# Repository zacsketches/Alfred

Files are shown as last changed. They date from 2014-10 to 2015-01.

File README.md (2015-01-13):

#Alfred

My Glow Worm Arduino based robotics framework on a Dagu Rover5 
platform.

The Alfred_master file contains the most advanced sketch that 
integrates the ultrasonic sensor with the bump sensors and
a light plant to provide some feedback on where the robot is
sensing obstructions.

Unfortunately, **AND THIS IS BIG**, I had to change the buffer size in
wire.h, twi.h, and hardwareSerial.h located in the Arduino libraries
in order to create enough room for this code to load on Arduino Uno.

If you aren't up for changing your libraries (using git to change 
between original/altered version of the libraries) you have two choices.  
Use the Mega or Due or use one of the small sketches in the dev_sketches
folder.

All these sketches use the tank tread style drive system that comes
stock on the Dagu 5.  The control system in all these robots picks
a control vector from the `control_vec.h` file.  

To tune the robot's response tweak the values in these control vectors.

Most sketch folders also include a `XXX_controller.h` file that
implements the decision logic for choosing a control vector based
on the results of the sensor input, whether that is the ultrasonic
sensor or the bump sensors or all of them.

##Development control systems

These sketches are located in the dev_sketches folder

 - Helen_bot - This version wanders around and reacts to bumping 
into things (Not a very politically correct name, but hey..she
freaked out in her later years even supporting Eugenics for crying
out loud (<a href="http://disabilityrightsgalaxy.com/the-untold-story-of-helen-keller/">ref</a>) so she had it coming).  
The Helen_bot is equipped with a set of bumpers printed on our 3D printer.
Files for the bumpers are in the prints folder.  Each bumper is wired with 
two momentary pushbutton switches which ground the input pin and allows the 
robot to react to the bump.  Each time a pin is grounded (because a 
bumper ran into something) the robot will back away from the
obstruction for a proscribed reaction time.  This reaction time can 
be set by calling `.set_maneuver_time(int)` on the helen_controller 
instance before calling the `.begin()` function.

- Whisker_bot - This version wanders too, but uses an ultrasonic 
sensor to attempt obstacle avoidance.  The sensor is good at detecting
walls and other obstacles, but has trouble with skinny chair legs
or other thin obstacles.  The header file `scanner.h` contains the
`Scanner_5pt` class which hides the processing necessary to 
control the sonar sensor and the servo it is mounted to as a scanner
object.

- Light_whisker_bot - This version doesn't change the control system
from the Whisker_bot.  However it adds feedback by incorporating a
bank of 5 LEDs to show which 'whisker' is getting obstruction 
feedback.  I still need to add the schematic for this light plant and
I will probably use our 3D printer to produce a new one.

- Message_test - This sketch demonstrates the print capabilities of
some Glow Worm Framework components.  Note that detailed printing 
from `GW::node`s is disabled by default.  This limits the memory
consumption for each sketch.  To turn printing on use the `#define`
statements at the top of each block.h file.

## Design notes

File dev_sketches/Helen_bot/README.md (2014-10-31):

Helen bot is the simplest possible implementation of my OOP Robot classes 
that take advantage of the bump sensors I recently built to wander around
and bump into stuff.  When a bump is detected it backs off and tries a new
direction.

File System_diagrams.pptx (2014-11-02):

## ALFRED: Bump and Wander Design

Helen_bot.ino

Two_bumper_msg

gw::Bumper* x2

Bumper_plant

Cmd_velocity_msg

Helen_controller

gw::Motor* 2

Rover_plant

NOTES:
- This is the simplest implementation of the Glow Worm system I’ve put together as a demonstration of how to build a publish and subscribe architecture with an open loop system.

## ALFRED: Bump and Wander with Light Plant

Helen_bot.ino

gw::Led* 5

Light_plant

Two_bumper_msg

gw::Bumper* x2

Bumper_plant

Cmd_led_msg
Cmd_velocity_msg

Helen_controller

gw::Motor* 2

Rover_plant

NOTES:
- The addition of the light plant requires the Helen_controller to publish two messages.
- The light plant also uses the I2C digital I/O expander and requires the Wire library which is a memory hog.

## ALFRED: Scan and Wander

Whisker_bot.ino

Five_pt_scan_msg

Servo.h x 1
Parallax PING))) x 1

Scanner_5pt

Cmd_velocity_msg

Whisker_controller

gw::Motor* 2

Rover_plant

NOTES:
- This bot implements obstacle avoidance by rotating an ultrasonic sensor with an attached servo.
- The Scanner_5pt block hides the implementation and control details for controlling the scan.

## ALFRED: Scan and Wander with Lights

Light_whisker_bot.ino

gw::Led* 5

Light_plant

Five_pt_scan_msg

Servo.h x 1
Parallax PING))) x 1

Scanner_5pt

Cmd_led_msg
Cmd_velocity_msg

Whisker_controller

gw::Motor* 2

Rover_plant

NOTES:
- This bot implements obstacle avoidance by rotating an ultrasonic sensor with an attached servo.
- This version adds the light plant to give a visual indication of which “whisker” was tripped by an obstacle.

## ALFRED: Scanner, Bumpers and Lights

Sbl_bot.ino

Two_bumper_msg

gw::Bumper* x2

Bumper_plant

gw::Led* 5

Light_plant

Five_pt_scan_msg

Servo.h x1
Parallax PING))) x 1

Scanner_5pt

Cmd_led_msg
Cmd_velocity_msg

Whisker_controller

gw::Motor* 2

Rover_plant

NOTES:
- This bot implements obstacle avoidance by rotating an ultrasonic sensor with an attached servo.
- This version adds the light plant to give a visual indication of which “whisker” was tripped by an obstacle.

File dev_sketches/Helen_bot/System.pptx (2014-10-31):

## ALFRED: Bump and Wander Design

Two_bumper_msg

Bumper_plant

gw::Bumper* x2

Cmd_velocity_msg

Helen_controller

Rover_plant

gw::Motor* 2

NOTES:

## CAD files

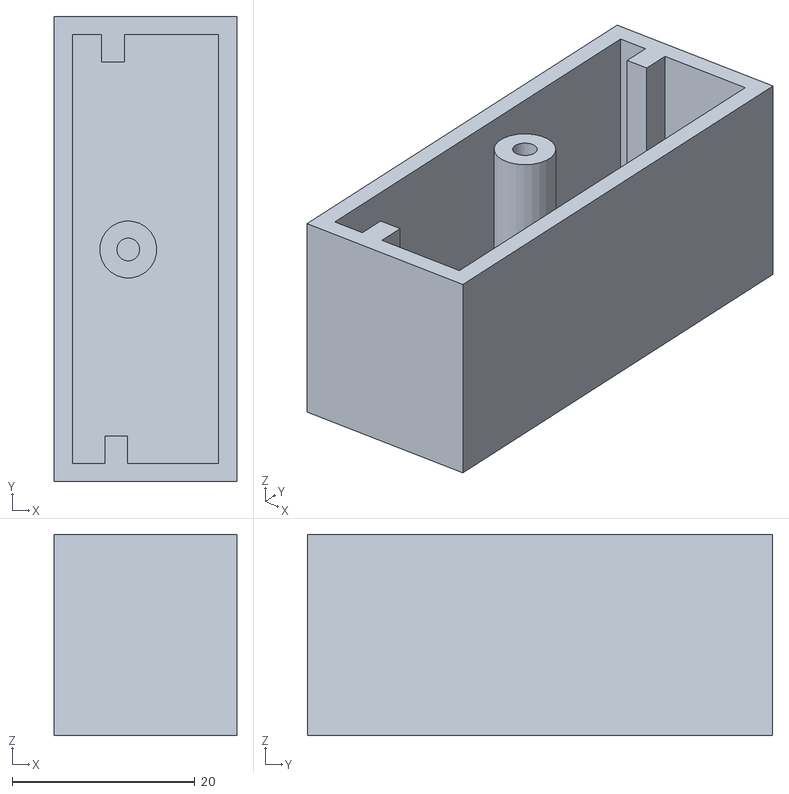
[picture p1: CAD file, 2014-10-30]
prints/bumper_plate_rev6.stl
20.0 x 51.0 x 22.0

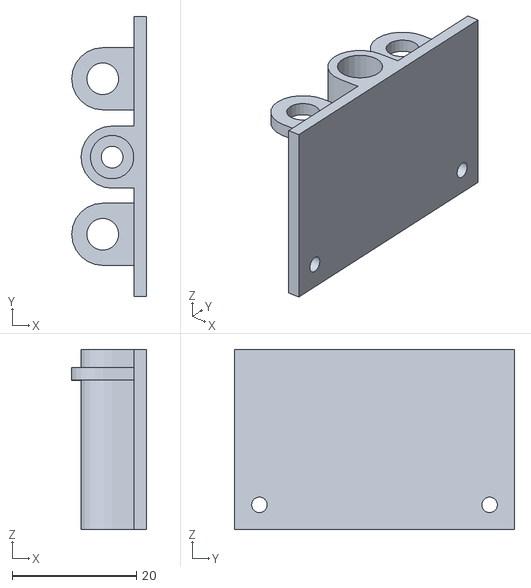
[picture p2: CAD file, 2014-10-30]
prints/Alfred_bumper_receiver_rev7.stl
12.0 x 45.0 x 29.0

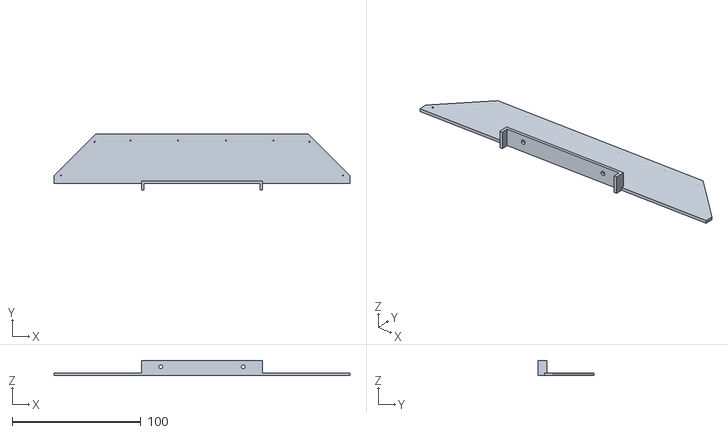
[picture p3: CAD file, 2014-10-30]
prints/Alfred_fender_rev1.stl
230.1 x 43.5 x 12.0

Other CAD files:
prints/Alfred_bumper_receiver_rev7.skp
prints/Alfred_fender_rev1.skp
prints/bumper_plate_rev6.skp

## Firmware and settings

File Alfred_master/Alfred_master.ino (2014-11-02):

//gw core
#include <clearinghouse.h>

//gw data structures
#include <Vector.h>
#include <Pair.h>

//gw messages
#include <messages/five_pt_scan.h>
#include <messages/cmd_velocity.h>
#include <messages/cmd_led.h>
#include <messages/bump.h>

//gw components
#include <blocks/scanner.h>
#include <blocks/rover_plant.h>
#include <blocks/light_plant.h>
#include <blocks/bumper_plant.h>

//local headers
#include "control_vec.h"
#include "whisker_controller.h"

//other 3rd party libraries
#include <Servo.h>		//for the scanner
#include <Wire.h>		//for the light plant

//Physical connections
const int servo_pin = 6;
const int ping_pin = 7;
const int servo_ctr = 88;
const int span_width = 130;

const int rt_motor_dir = 2;
const int rt_motor_spd = 3;
const int lt_motor_dir = 4;
const int lt_motor_spd = 5;

const int rt_bumper_pin = 12;
const int lt_bumper_pin = 13;

/*------------Required to initiate the Glow Worm Framework---------------*/
gw::Clearinghouse ch;
int gw::Message::msg_count = 0;
int gw::Node::node_count = 0;

/*------------Create a set of global messsages---------------------------*/
Two_bumper_msg bumper_msg;
Five_pt_scan_msg five_pt_scan_msg;
Cmd_velocity_msg cmd_velocity_msg;
Cmd_led_msg cmd_led_msg;

/*------------Construct the system components----------------------------*/
//Scanner
Scanner_5pt scanner(servo_pin, ping_pin, servo_ctr, span_width);
//Bumpers and bumper plant
Bumper* lt_bumper = new Bumper("lt_bump", lt_bumper_pin, Position::lt);
Bumper* rt_bumper = new Bumper("rt_bump", rt_bumper_pin, Position::rt);
Bumper_plant bumper_plant;    
//Motors and plant
gw::Motor* mtr_lt = new gw::Motor("lt", lt_motor_dir, lt_motor_spd);  
gw::Motor* mtr_rt = new gw::Motor("rt", rt_motor_dir, rt_motor_spd);
Rover_plant plant(2);
//LEDs and light_plant
//  signature: Led(const char* name, Port::port pt, State::state s = State::off)
Led* led1 = new Led("far_lt",  Port::p0);
Led* led2 = new Led("near_lt", Port::p1);
Led* led3 = new Led("mid",     Port::p2);
Led* led4 = new Led("near_rt", Port::p3);
Led* led5 = new Led("far_rt",  Port::p4);
Light_plant light_plant;
//controller
Whisker_controller controller;

void setup() {
	Serial.begin(115200);
	Serial.println();

	ch.list();

	//start the scanner
	scanner.begin();
//	scanner.print();
	
	//attach bumpers to the bumper plant
	bumper_plant.attach(lt_bumper);
	bumper_plant.attach(rt_bumper);
	bumper_plant.begin();
	bumper_plant.print();

	//attach motors to the plant
	plant.attach(mtr_lt);
	plant.attach(mtr_rt);
//	plant.print();

	//attach LEDs and begin the light_plant
	light_plant.attach(led1);
	light_plant.attach(led2);
	light_plant.attach(led3);
	light_plant.attach(led4);
	light_plant.attach(led5);
	light_plant.begin();
//	light_plant.print();

	//begin the controller AFTER beginning the scanner
	//the scanner computes the scan point angles in its
	//begin method, and the controller needs this data in
	//its own begin method.
	controller.begin();
//      controller.print();
        
	delay(3000);
}

void loop() {
  bumper_plant.run();
  scanner.run();
  controller.run();
  plant.run();
  light_plant.run();

/*------Inspect global messages-----*/  
  //cmd_velocity_msg.print();
  //cmd_led_msg.print();
  //five_pt_scan_msg.print();
  bumper_msg.print();

/*-----Contoller debug-------------*/
//  controller.show_trips();
//  controller.show_scan_data(); 
//  controller.show_sensor_state();
//  controller.show_dc();
//  controller.show_bs();
//  controller.show_active_control();
   
}

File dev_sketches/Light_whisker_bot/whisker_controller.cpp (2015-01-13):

#include "whisker_controller.h"

/* void Whisker_controller::update_scan_vector(Vector<Scan_pt>& vec, Five_pt_scan_msg& msg) {
    update_range(vec, msg.p4);
    update_range(vec, msg.p2);
    update_range(vec, msg.p0);
    update_range(vec, msg.p1);
    update_range(vec, msg.p3);
} */

//*******************************************************************
//*                         CONSTRUCTOR
//*******************************************************************
Whisker_controller::Whisker_controller()
    :Node("whisker_cont"),
    scan_sub(&five_pt_scan_msg, &ch, local_scan_msg),
    pub(&cmd_velocity_msg, &ch, local_msg),
    pub2(&cmd_led_msg, &ch, local_led_msg)
{    
    //b_state = Bump_state::clear;
    sensor_state = 0;
    dc_state = Danger_close_state::clear;
}

//*******************************************************************
//*                         REQUIRED VIRTUAL FUNCTIONS
//*******************************************************************
void Whisker_controller::begin() {
    scan_sub.update();  //load the local message with the headings in
                        //the scan
        
    //set up trip points for each heading
    int heading4 = local_scan_msg.p4.heading();
    int heading2 = local_scan_msg.p2.heading();
    int heading0 = local_scan_msg.p0.heading();
    int heading1 = local_scan_msg.p1.heading();
    int heading3 = local_scan_msg.p3.heading();
    
    // trips.reserve(5);
    trips.push_back(Trip_pt(heading4, side_trip,        0x10));
    trips.push_back(Trip_pt(heading2, off_the_bow_trip, 0x08));
    trips.push_back(Trip_pt(heading0, dead_ahead_trip,  0x04));
    trips.push_back(Trip_pt(heading1, off_the_bow_trip, 0x02));
    trips.push_back(Trip_pt(heading3, side_trip,        0x01));
    	
    //set up the original copy of the scan_data vector;
    scan_data.reserve(5);
    scan_data.push_back(Scan_pt(heading4, clear_distance));
    scan_data.push_back(Scan_pt(heading2, clear_distance));
    scan_data.push_back(Scan_pt(heading0, clear_distance));
    scan_data.push_back(Scan_pt(heading1, clear_distance));
    scan_data.push_back(Scan_pt(heading3, clear_distance));
}

void Whisker_controller::run() {
 
        scan_sub.update();
        
	    update_range(scan_data, local_scan_msg.p4);
	    update_range(scan_data, local_scan_msg.p2);
	    update_range(scan_data, local_scan_msg.p0);
	    update_range(scan_data, local_scan_msg.p1);
	    update_range(scan_data, local_scan_msg.p3);

//        b_state = calc_b_state();
        dc_state = calc_dc_state();
        sensor_state = calc_sensor_state();
        
        active_control_vec = get_base_vector();
        
		publish_message();
		publish_led_message();
}

//*******************************************************************
//*                         HELPER FUNCTIONS
//*******************************************************************
/*
Bump_state::bump_state Whisker_controller::calc_b_state() {
    Bump_state::bump_state res = Bump_state::clear;
    
    if (rt_local_bumper_msg.pressed) res = Bump_state::rt_bump;
    if (lt_local_bumper_msg.pressed) res = Bump_state::lt_bump;
    
    return res;
}
*/

void Whisker_controller::update_range(Vector<Scan_pt>& vec, const Scan_pt& pt) {
    for(int i = 0; i < vec.size(); ++i) {
        if(pt.heading() == vec[i].heading()){
            vec[i].set_range(pt.range());
        }
    }
}

Danger_close_state::dc Whisker_controller::calc_dc_state() {
/*
    TODO implement a more general version of danger_close() that is based on the 
    center heading of the scan +/- some offset instead of hard coded to the
    middle three sensors.
*/
    Danger_close_state::dc res = Danger_close_state::clear;

    //only take danger close from the middle three sensors
    int range0 = local_scan_msg.p0.range();
    int range1 = local_scan_msg.p1.range();
    int range2 = local_scan_msg.p2.range();

    if(range0 < dc_dist) res = Danger_close_state::danger_close;
    if(range1 < dc_dist) res = Danger_close_state::danger_close;
    if(range2 < dc_dist) res = Danger_close_state::danger_close;

    return res;
}

byte Whisker_controller::calc_sensor_state(){

    byte res = 0x00;
    
    // the Vector<Trip_pt> trips contains all the headings and trip distances for the
    // controller.  Compare the data in the vector scan_data against the trip distances
    // and set the result byte accordingly.  See the whisker diagram in the .h file 
    // to undertand the bit shifting required to create the mask for each heading.

    for(int i = 0; i < scan_data.size(); ++i) {
        for(int j = 0; j < trips.size(); ++j) {
            //if the scan heading matches the trip heading then compare ranges
            if(scan_data[i].heading() == trips[j].heading()){
                if(scan_data[i].range() < trips[j].range()) {
                    res |= trips[j].flag();
                }
            }
        }
    }
    return res;
}
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

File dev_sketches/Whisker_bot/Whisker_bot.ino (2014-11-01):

/*
	Whisker_bot is an integration of the Glow_worm 5pt Scanner class
	with the Dagu Rover5 chassis.
	
	The robot uses a single Parallax PING))) ultrasonic sensor mounted
	to a servo that rotates it to five different Lines of Bearing(LOBs).
	The range aquired at each LOB is used to wander around trying to
	do obstacle avoidance.
*/ 

//gw core
#include <clearinghouse.h>

//gw data structures
#include <Vector.h>
#include <Pair.h>

//gw messages
#include <messages/five_pt_scan.h>
#include <messages/cmd_velocity.h>

//gw components
#include <blocks/rover_plant.h>
#include <blocks/scanner.h>

//local headers
#include "control_vec.h"
#include "whisker_controller.h"

//other 3rd party libraries
#include <Servo.h>

//Physical connections
const int servo_pin = 6;
const int ping_pin = 7;
const int servo_ctr = 88;
const int span_width = 130;

const int rt_motor_dir = 2;
const int rt_motor_spd = 3;
const int lt_motor_dir = 4;
const int lt_motor_spd = 5;

/*------------Required to initiate the Glow Worm Framework---------------*/
gw::Clearinghouse ch;
int gw::Message::msg_count = 0;
int gw::Node::node_count = 0;

/*------------Create a set of global messsages---------------------------*/
Five_pt_scan_msg five_pt_scan_msg;
Cmd_velocity_msg cmd_velocity_msg;

/*------------Construct the system components----------------------------*/
Scanner_5pt scanner(servo_pin, ping_pin, servo_ctr, span_width);
gw::Motor* mtr_lt = new gw::Motor("lt", lt_motor_dir, lt_motor_spd);  
gw::Motor* mtr_rt = new gw::Motor("rt", rt_motor_dir, rt_motor_spd);
Rover_plant plant(2);

Whisker_controller controller;

void setup() {
  Serial.begin(115200);
  Serial.println();
  
  ch.list();
  
  scanner.begin();
  scanner.print();
  
  //attach motors to the Rover_plant
  plant.attach(mtr_lt);
  plant.attach(mtr_rt);
  plant.print();
  
  controller.begin();
  controller.print();
//  controller.show_trips();
//  controller.show_scan_data();

  delay(3000);
}

void loop() {
  scanner.run();
//  five_pt_scan_msg.print();  

  controller.run();
//  controller.show_trips();
//  controller.show_scan_data(); 
//  controller.show_sensor_state();
//  controller.show_dc();
//  controller.show_bs();
//  controller.show_active_control();

  plant.run();

/*------Inspect global messages-----*/  
  cmd_velocity_msg.print();
//  five_pt_scan_msg.print();
   
}

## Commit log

2014-10-30 Added refs and prints folder
    [Alfred_bumper_receiver_rev7.skp, Alfred_bumper_receiver_rev7.stl, Alfred_fender_rev1.skp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]
2014-11-01 Functional Helen_bot
    - added time management to the bumper controller
    - tuned the control vector values to give a balanced
    response on both CW and CCW turns.
    - corrected the pin numbering in the main sketch for how the
    physical bumpers are actually wired.
    [Helen_bot.ino]
2014-11-01 Added a new system design for bump w/light plant
    - Added I2C expander datasheet to refs
    - Used the Glow_worm light_plant to add lights to
    the reaction when a bumper gets pressed.
2014-11-02 fixed bug with scan starting off 0x1F
    [whisker_controller.cpp]
2014-11-02 Functioning SBL loaded on Alfred!!!
    - BIG NOTE: I had to decrease the buffer sized in wire.h,
    twi.h and hardwareSerial.h in order for there to be enough
    memory to load.
